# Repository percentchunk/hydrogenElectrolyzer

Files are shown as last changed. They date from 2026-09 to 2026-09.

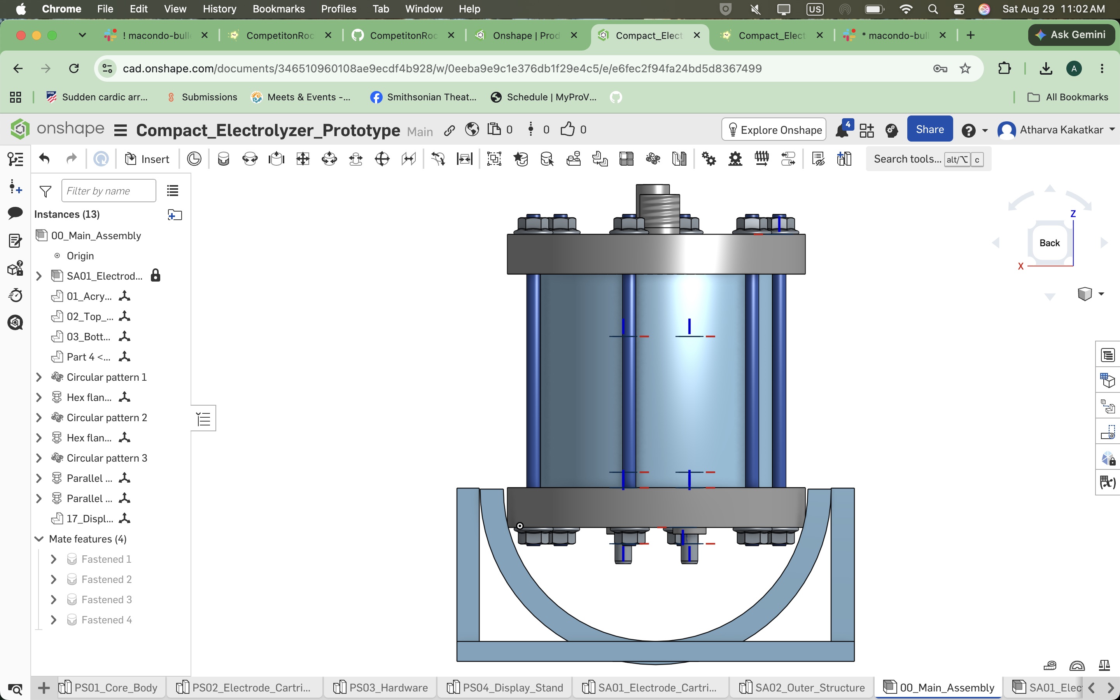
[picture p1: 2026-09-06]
Image files/D.jpeg

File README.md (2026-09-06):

# Compact Water Electrolysis Demonstrator

A compact, modular water electrolysis demonstrator inspired by the small “arc reactor” aesthetic.

The project is built around a cylindrical chamber, removable internal electrode cartridge, external structural tie rods, dedicated fill/drain and vent ports, and a custom upright PLA display stand.

The mechanical design was created in Onshape and has already been checked with a full-size 3D-printed fit prototype. The prototype confirmed that the main geometry, stand fit, cap alignment, cartridge clearance, and overall sizes work as intended.

---

## Project Status

- Mechanical CAD v1 complete
- Full-size PLA fit prototype printed
- Stand fit validated
- Core geometry and clearances checked
- Main assembly organized in Onshape
- Hardware sourcing and BOM planning in progress
- Cosmetic arc-reactor shell and lighting planned for later

---

## Design Overview

### Main Chamber

- Clear cylindrical body
- 70 mm outer diameter
- 66 mm inner diameter
- 60 mm chamber length
- Removable top and bottom caps
- Six external structural tie rods around the chamber

### Electrode Cartridge

- Removable internal cartridge
- 10 stainless-steel disks
- Two stainless-steel conductive rods
- Cartridge designed to slide out with the top section
- Disk spacing kept modular so the spacer design can be changed later

### Top Cap

- Dedicated fill/drain port
- Separate atmospheric vent
- Removable design for chamber access

### Bottom Cap

- Positive and negative terminal locations
- Internal rods aligned with the terminal positions
- Electrical isolation features planned around the pass-throughs

### Display Stand

- Printed in PLA
- Upright U-shaped cradle
- Sized around the 90 mm cap
- 92 mm cradle inner diameter
- Reinforced with support ribs and fillets
- Designed to support the main body without loading the terminals

---

## Physical Prototype

A full-size PLA prototype was printed before ordering the final metal hardware.

The prototype was used to verify:

- overall scale
- stand fit
- cap geometry
- cartridge clearance
- terminal clearance
- tie-rod alignment
- assembly proportions

The printed cap measured approximately 89.5 mm compared with the 90 mm CAD dimension, which was close enough to validate the overall mechanical layout.

The prototype is currently held together with temporary printed/placeholding hardware rather than the final metal threaded rods and nuts.

### Project Photos

#### CAD Assembly
Screenshot 2026-09-06 at 1 22 10 AM

#### Full-Size Prototype


#### Stand Fit
Screenshot 2026-09-06 at 1 26 51 AM

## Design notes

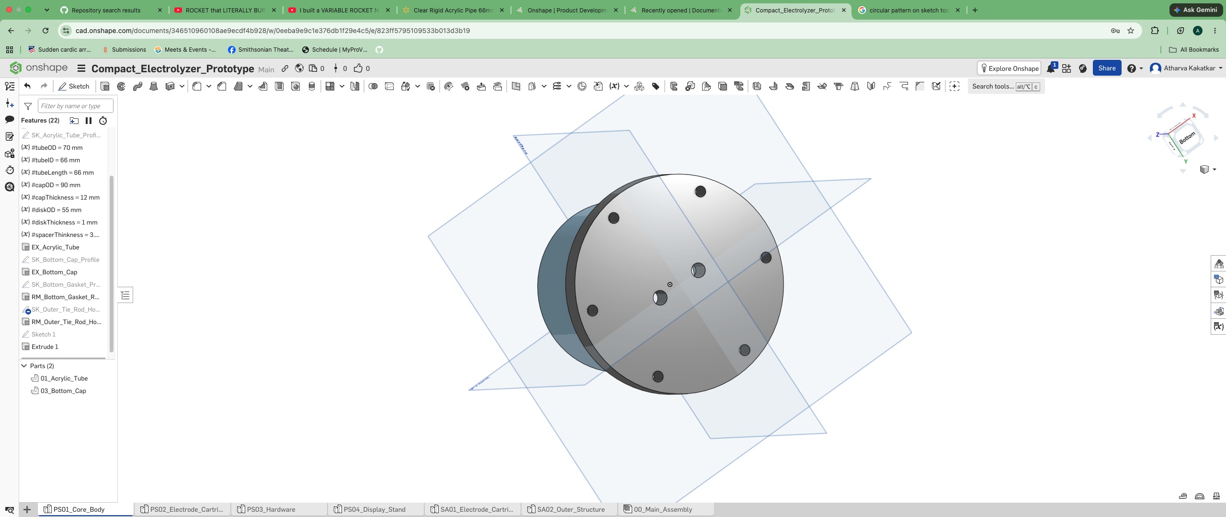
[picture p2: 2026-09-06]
Image files/Draft Cap.jpeg

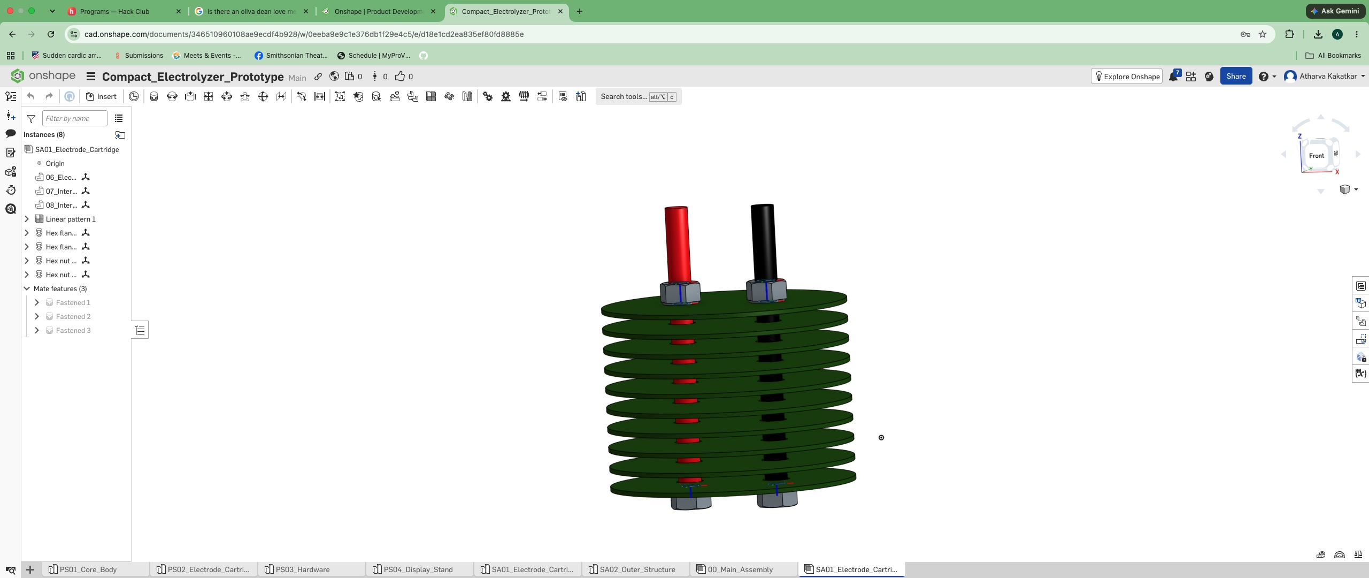
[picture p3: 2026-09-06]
Image files/Main Body.jpeg

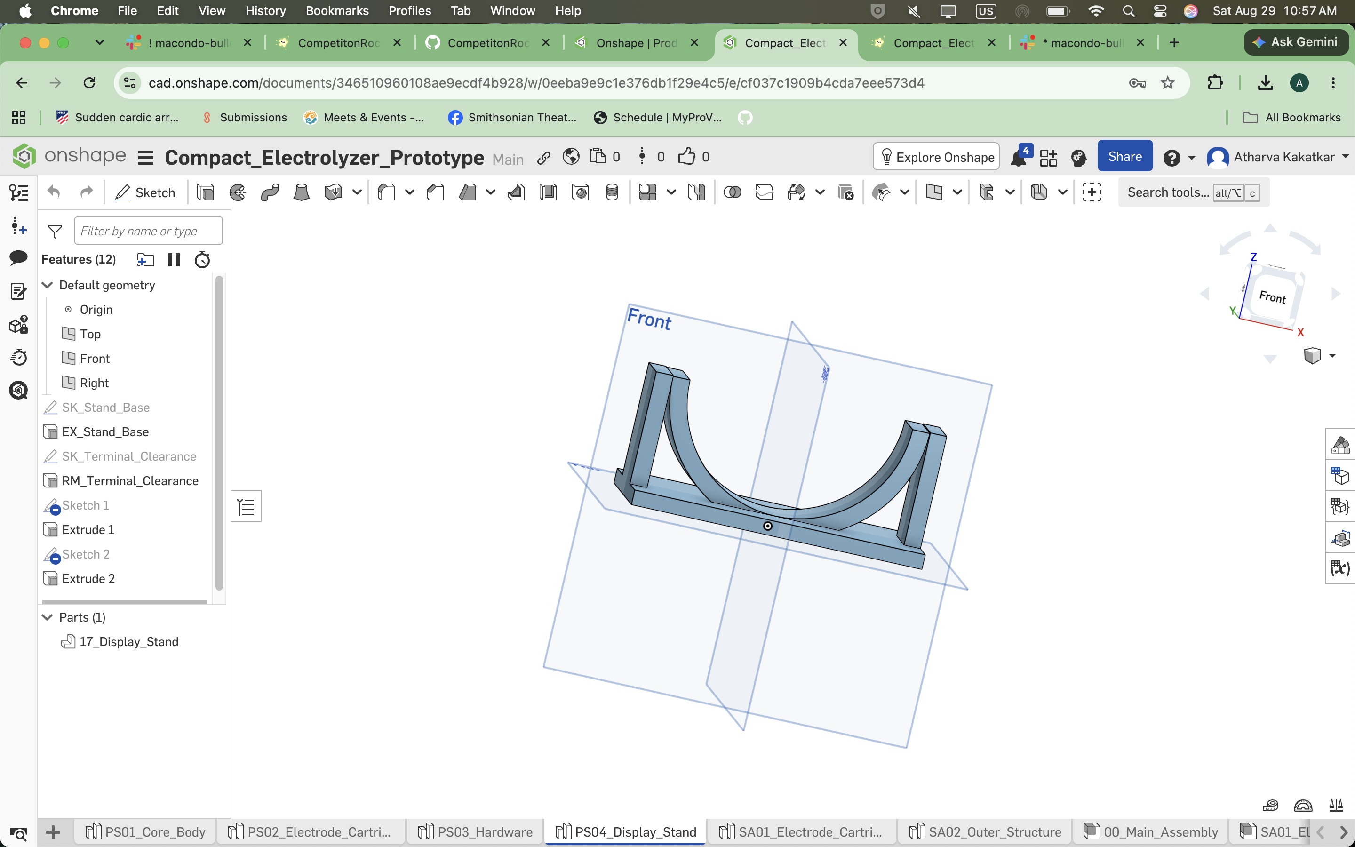
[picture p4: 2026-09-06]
Image files/C.jpeg

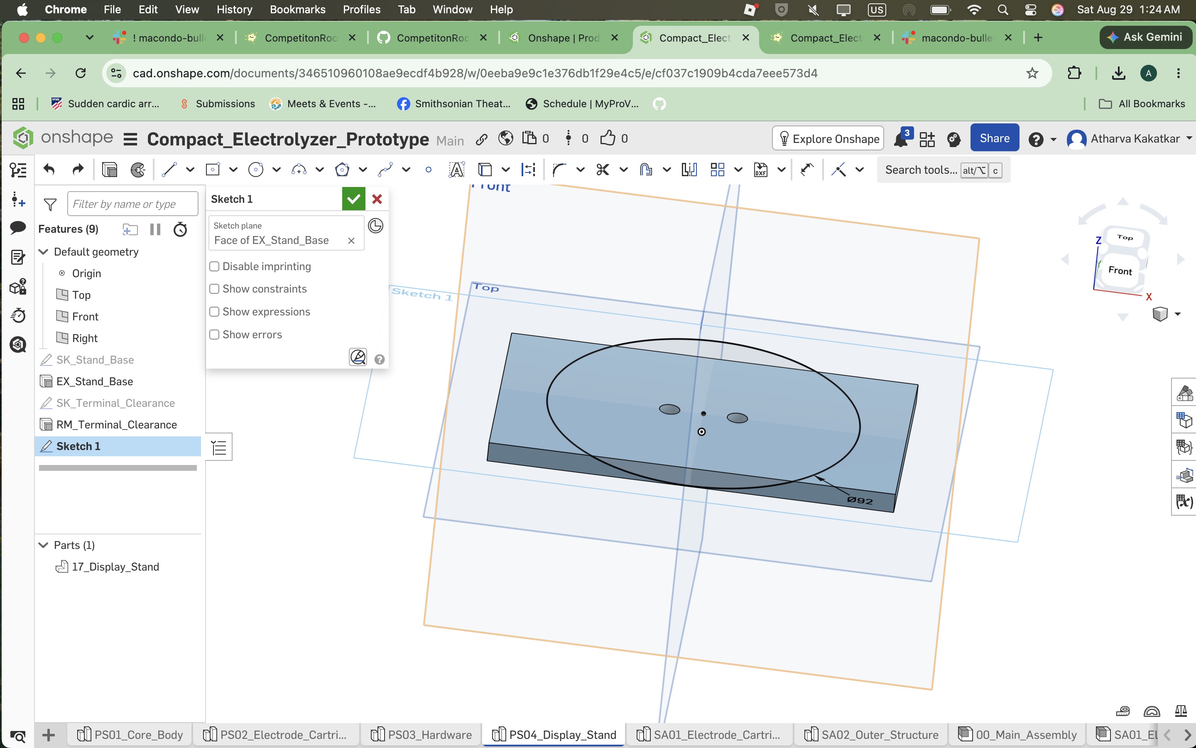
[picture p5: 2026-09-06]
Image files/B.jpeg

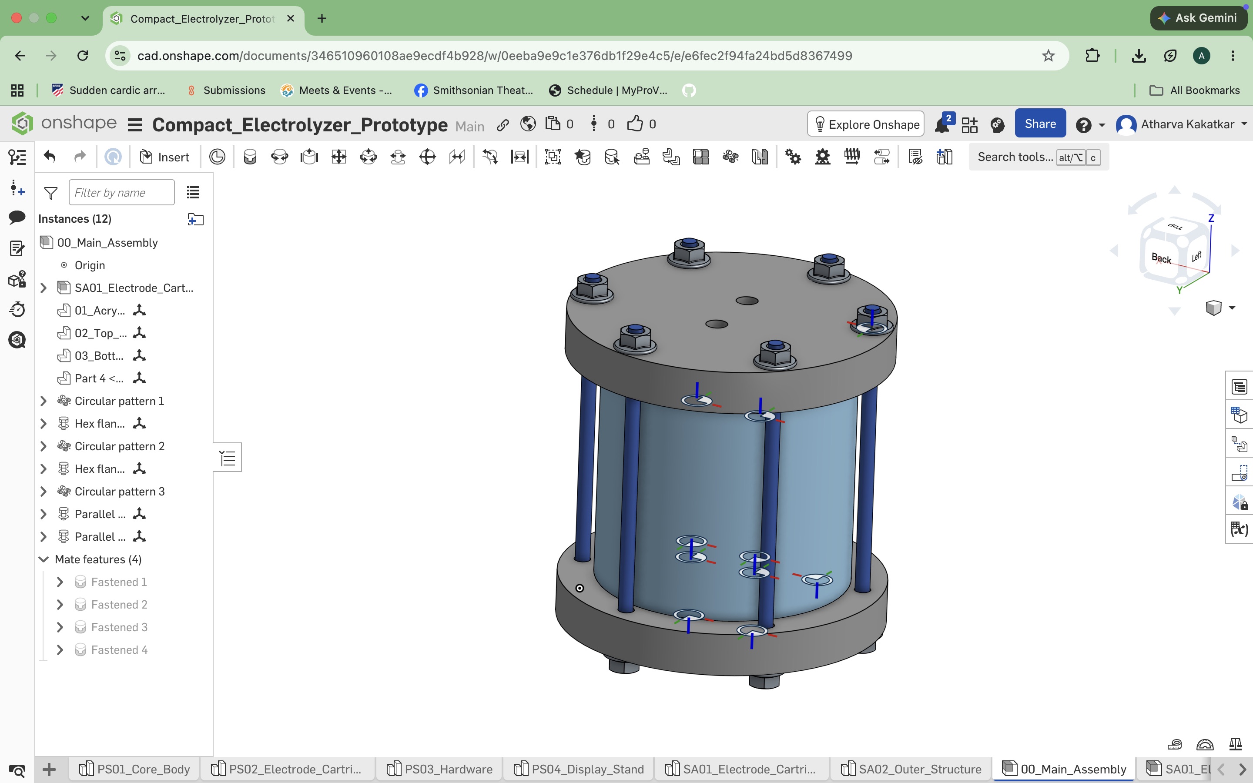
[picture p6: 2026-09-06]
Image files/A.jpeg

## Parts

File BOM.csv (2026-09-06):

Part | Quantity | Price (USD) | Product Link
Uxcell clear rigid acrylic tube 70 mm OD / 66 mm ID / 305 mm length | 1 tube | TBD | https://www.walmart.com/ip/Uxcell-Clear-Rigid-Acrylic-Pipe-41mm-1-5-8-ID-x-45mm-OD-x-305mm-12-2mm-3-32-Wall-Round-Tube/941231133
Custom 90 mm top cap | 1 | TBD | Custom / machined
Custom 90 mm bottom cap | 1 | TBD | Custom / machined
M4 threaded rods approx. 100 mm | 6 rods | TBD | TBD
M4 x 0.7 stainless-steel hex nuts | 12 | TBD | TBD
M4 flat washers | 12 | TBD | TBD
Top gasket | 1 | TBD | TBD
Bottom gasket | 1 | TBD | TBD
55 mm stainless-steel disks 1 mm thick | 10 | TBD | Custom / TBD
Stainless-steel internal conductive rods 65 mm | 2 rods | TBD | TBD
Internal rod retaining nuts | 4 | TBD | TBD
Nonconductive disk spacers | 9 | TBD | 3D printed / custom
Positive terminal hardware | 1 set | TBD | TBD
Negative terminal hardware | 1 set | TBD | TBD
Terminal insulating bushings | 2 | TBD | TBD
Fill/drain fitting | 1 | TBD | TBD
Fill/drain cap | 1 | TBD | TBD
Atmospheric vent fitting | 1 | TBD | TBD
PLA display stand | 1 | Already printed | Custom 3D print
PLA full-size fit prototype | 1 | Already printed | Custom 3D print
Future arc-reactor cosmetic shell | 1 | TBD | Custom 3D print
Future LED lighting | 1 set | TBD | TBD
Current project total |  | TBD

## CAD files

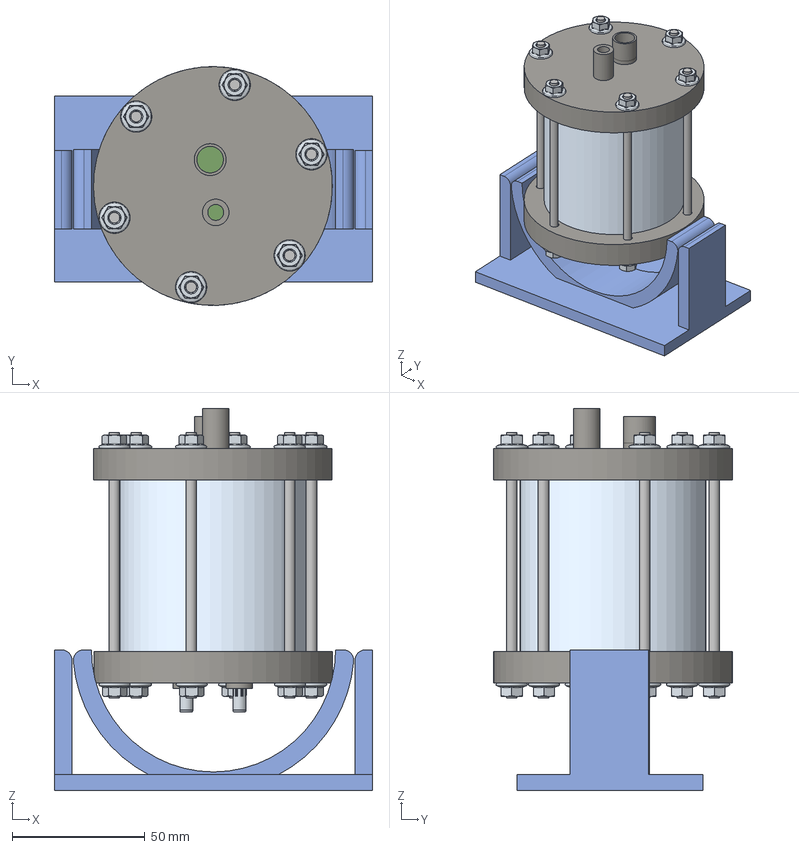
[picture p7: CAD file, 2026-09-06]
Compact_Electrolyzer_protoype/StepFiles/00_Main_Assembly (2).step
120.0 x 90.0 x 143.9 mm
17_Display_Stand
Hex flange nut M5x0.80 x 14
04_outer_chamber_connection x 6
03_Bottom_Cap
02_Top_Cap
08_Internal_Rod_Negative
06_Electrode_Disk x 10
Hex nut style 1 grade A & B M5x0.8 x 2
07_Internal_Rod_Positive
01_Acrylic_Tube
Parallel pin 5 x 12 x 2

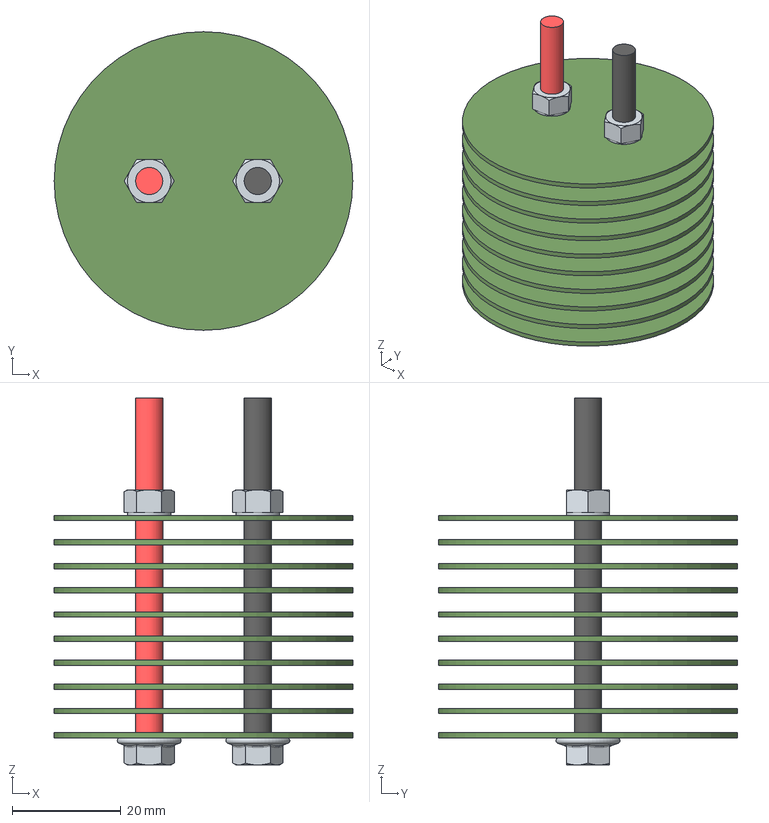
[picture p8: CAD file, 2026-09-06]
Compact_Electrolyzer_protoype/StepFiles/SA01_Electrode_Cartridge.step
55.0 x 55.0 x 67.6 mm
06_Electrode_Disk x 10
07_Internal_Rod_Positive
Hex flange nut M5x0.80 x 2
Hex nut style 1 grade A & B M5x0.8 x 2
08_Internal_Rod_Negative

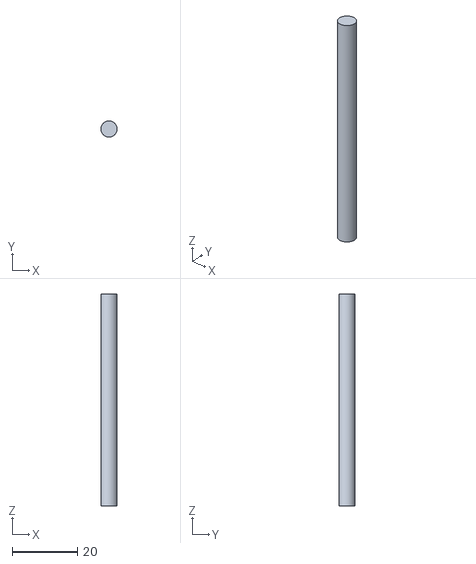
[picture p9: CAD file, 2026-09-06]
Compact_Electrolyzer_protoype/STL Files/PS02_Electrode_Cartridge - 08_Internal_Rod_Negative.stl
5.00 x 4.99 x 65.0

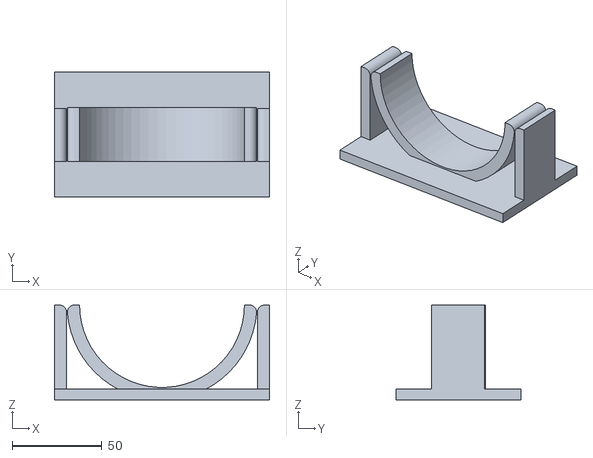
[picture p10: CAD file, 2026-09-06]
Compact_Electrolyzer_protoype/STL Files/PS04_Display_Stand - 17_Display_Stand.stl
120.0 x 70.0 x 53.0

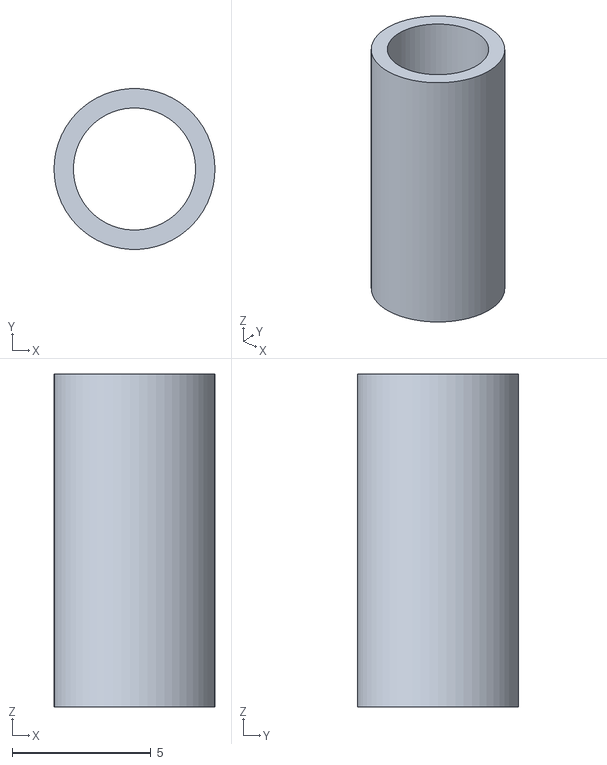
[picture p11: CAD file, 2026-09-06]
Compact_Electrolyzer_protoype/STL Files/PS01_Core_Body - 06_Insulator_negative.stl
5.80 x 5.79 x 12.0

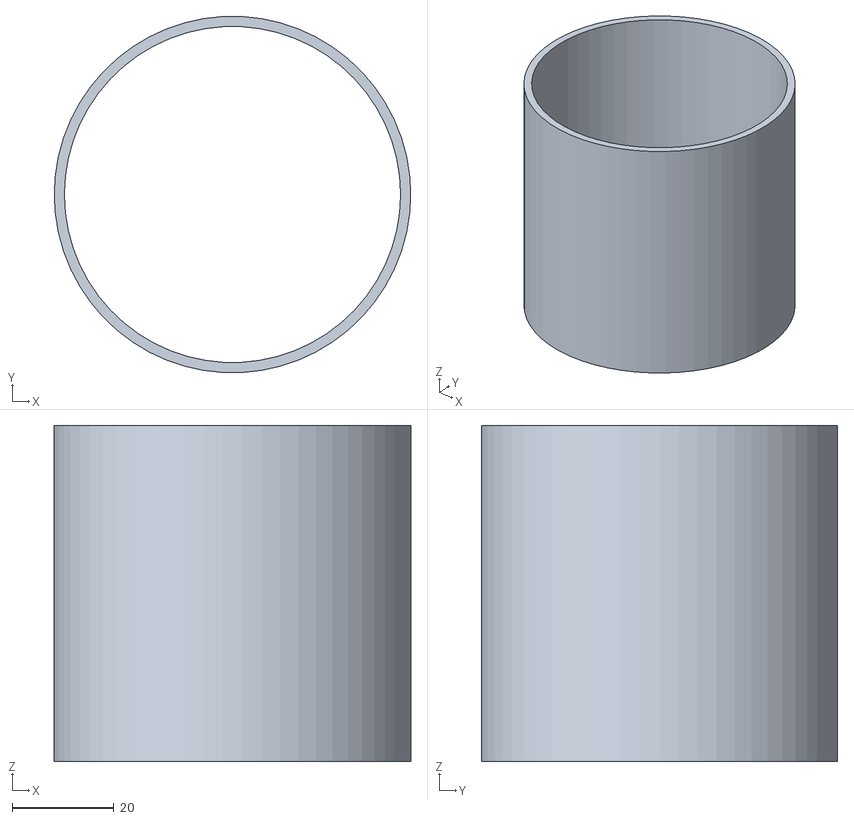
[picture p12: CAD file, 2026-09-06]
Compact_Electrolyzer_protoype/STL Files/PS01_Core_Body - 01_Acrylic_Tube.stl
70.0 x 69.9 x 66.0

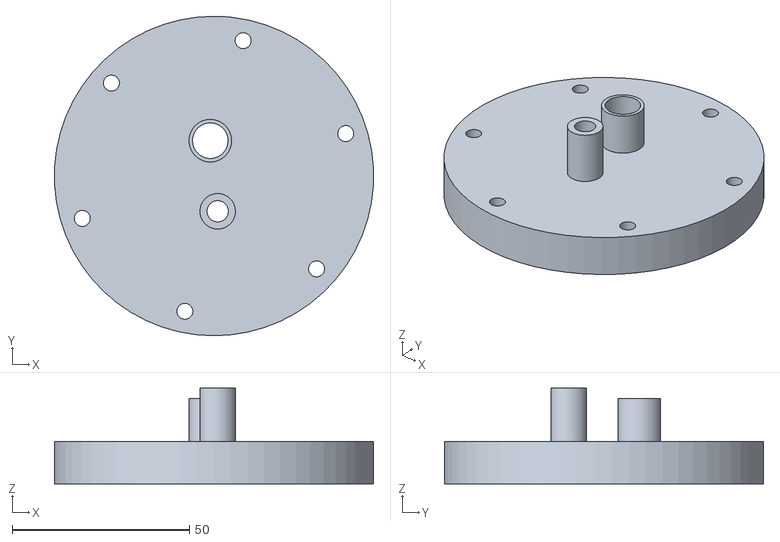
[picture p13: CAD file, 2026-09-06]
Compact_Electrolyzer_protoype/STL Files/PS01_Core_Body - 02_Top_Cap.stl
89.9 x 90.0 x 27.0

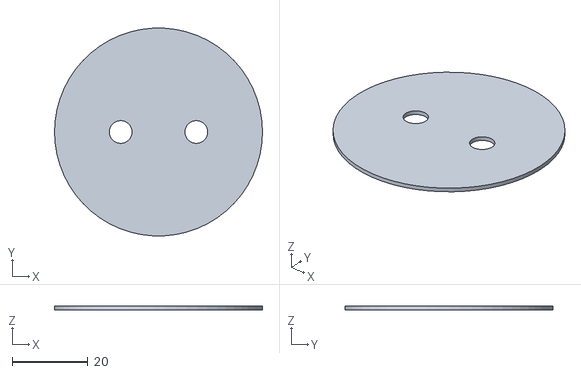
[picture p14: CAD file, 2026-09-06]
Compact_Electrolyzer_protoype/STL Files/PS02_Electrode_Cartridge - 06_Electrode_Disk.stl
55.0 x 54.9 x 1.00

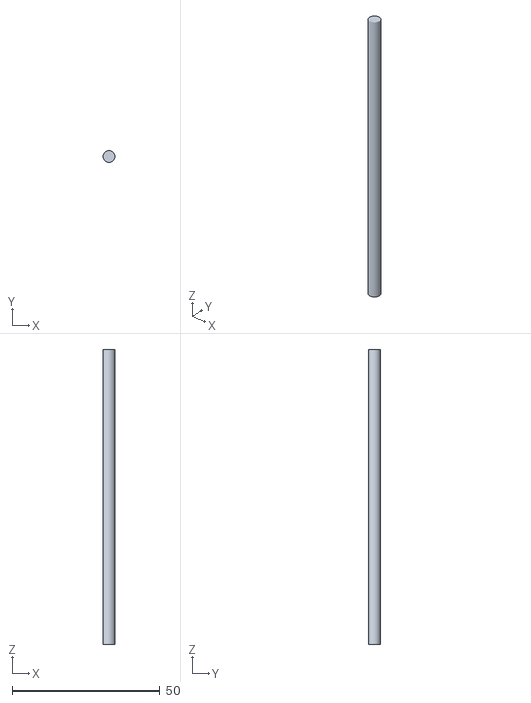
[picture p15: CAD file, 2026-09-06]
Compact_Electrolyzer_protoype/STL Files/PS01_Core_Body - 04_outer_chamber_connection.stl
4.00 x 3.99 x 100.0

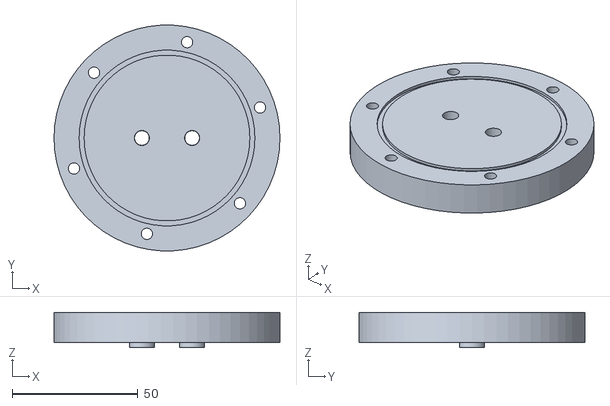
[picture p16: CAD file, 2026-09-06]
Compact_Electrolyzer_protoype/STL Files/PS01_Core_Body - 03_Bottom_Cap.stl
90.0 x 89.9 x 14.0

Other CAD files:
Compact_Electrolyzer_protoype/STL Files/00_Main_Assembly.stl
Compact_Electrolyzer_protoype/STL Files/PS01_Core_Body - 05_Insulator_postive.stl
Compact_Electrolyzer_protoype/STL Files/PS02_Electrode_Cartridge - 07_Internal_Rod_Positive.stl
Compact_Electrolyzer_protoype/STL Files/SA01_Electrode_Cartridge.stl
